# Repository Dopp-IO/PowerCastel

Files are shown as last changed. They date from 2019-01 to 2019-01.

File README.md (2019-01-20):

# PowerCastel
Tiny castellated adaptation of Adafruit PowerBoost 1000C.

Part	Value	        Package  
C1	  10uF	        C0603  
C2  	2.2uF	        C0603  
C4	  0.1uF       	C0603  
C6  	100uF	        C0805  
C7  	10uF	        C0603  
L1  	6.8uH	        INDUCTOR_5X5MM_TDK_VLC5045  
R1  	1.87M	        R0603  
R2  	340K	        R0603  
R3  	1.87M	        R0603  
R4  	200K	        R0603  
R6  	270K	        R0603  
R7  	100K	        R0603  
R13 	200K	        R0603  
R16 	1.0K	        R0603  
R17 	100K	        R0603  
THERM	15K	          R0603  
T1    MMUN2114      SC59-BEC  
U1	  TPS61090RSAR	PVQFN-16  
U2	  MCP73871	    QFN20_4MM

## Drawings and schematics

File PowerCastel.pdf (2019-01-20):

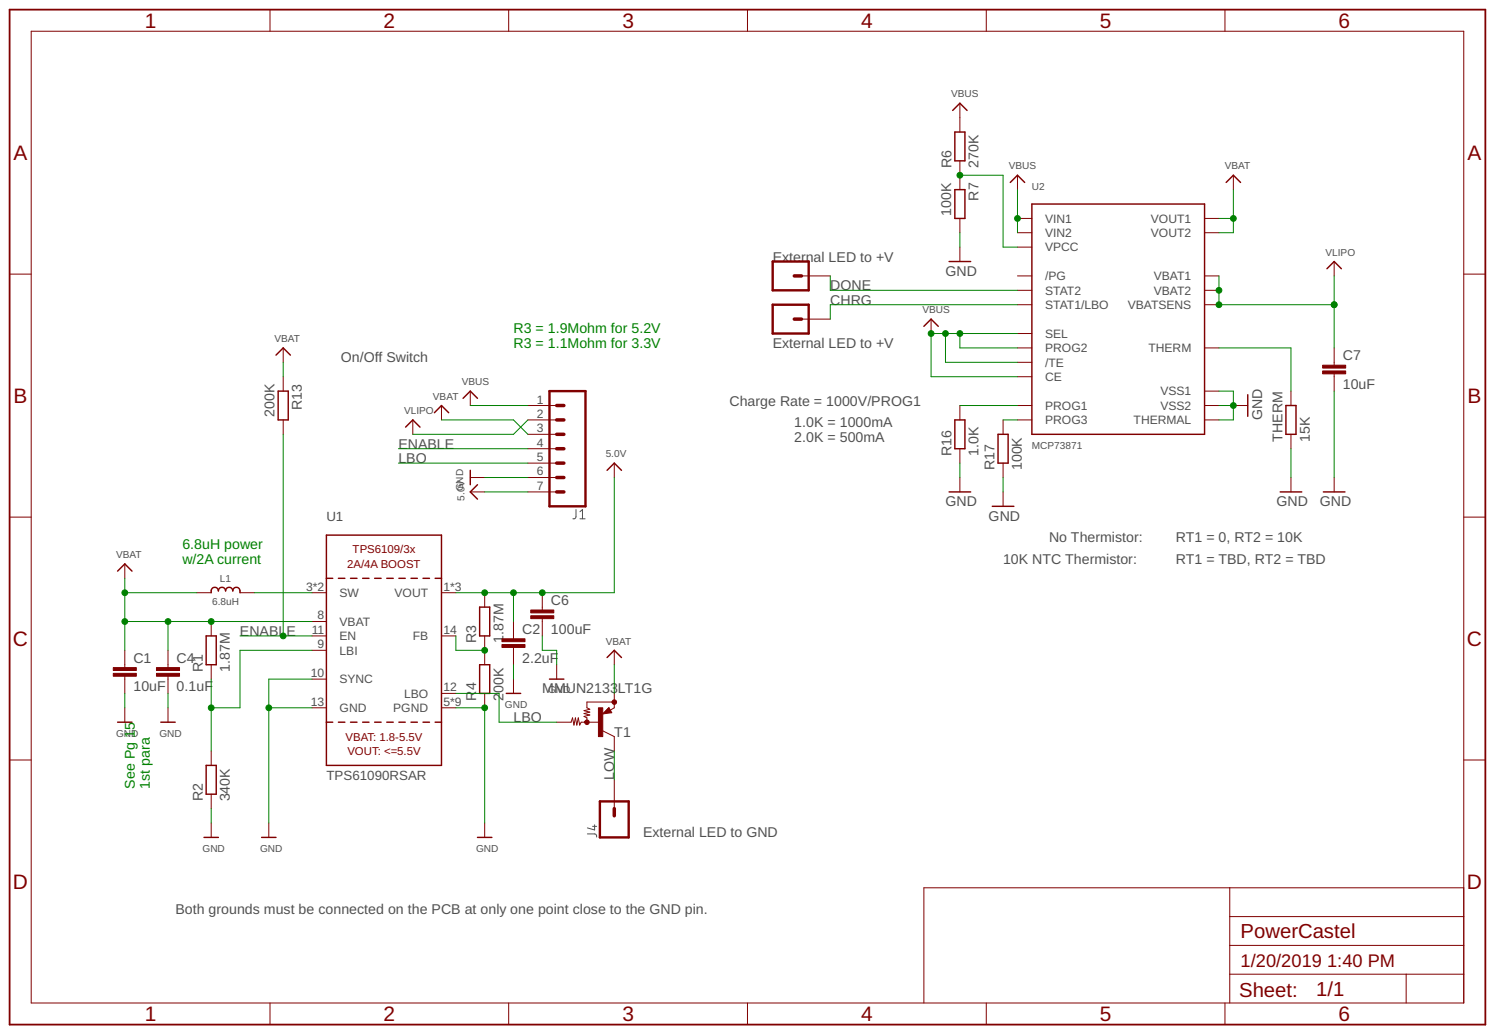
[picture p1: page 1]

External LED to GND

Both grounds must be connected on the PCB at only one point close to the GND pin.

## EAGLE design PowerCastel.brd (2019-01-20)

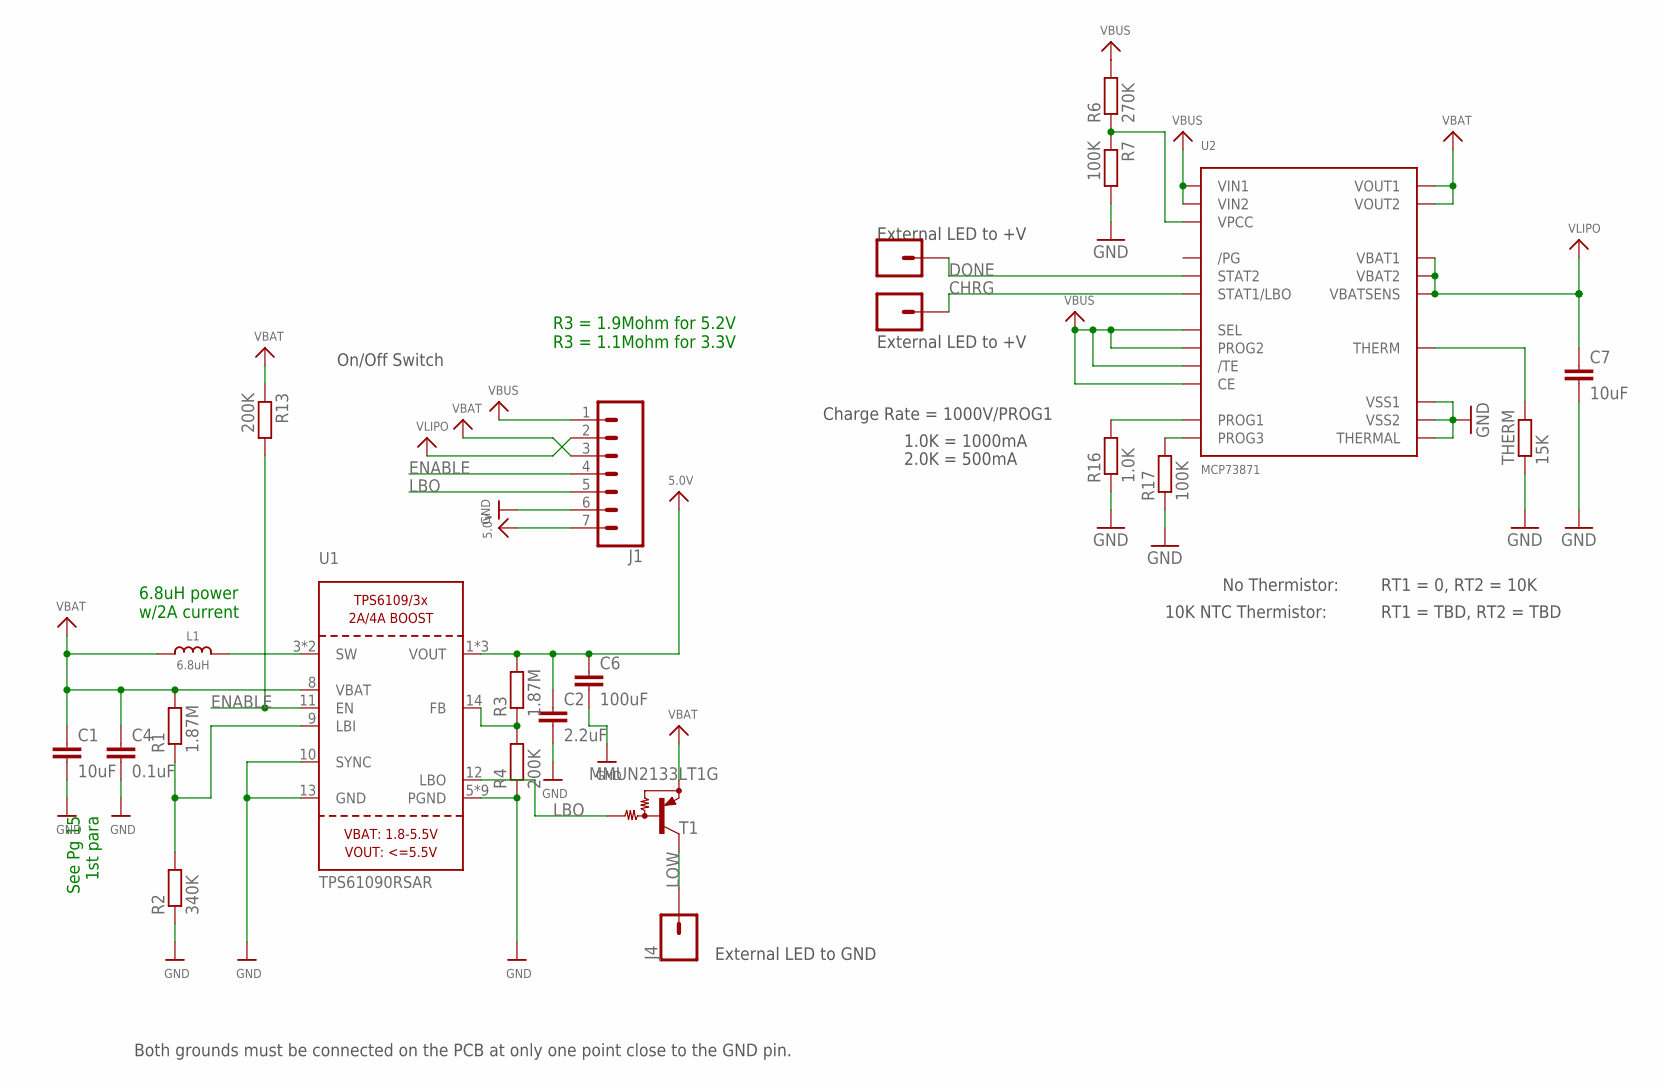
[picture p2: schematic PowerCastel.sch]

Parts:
C1, C7: 10uF; C0603
C2: 2.2uF; C0603
C4: 0.1uF; C0603
C6: 100uF; C0805
J1: CONN_07NO_SILK; 1X07_NO_SILK
J2, J3, J4: CONN_01PTH_NO_SILK_YES_STOP; 1X01_NO_SILK
L1: 6.8uH; INDUCTOR_5X5MM_TDK_VLC5045
R1, R3: 1.87M; R0603
R2: 340K; R0603
R4, R13: 200K; R0603
R6: 270K; R0603
R7, R17: 100K; R0603
R16: 1.0K; R0603
T1: MMUN2133LT1G; SC59-BEC
THERM: 15K; R0603
U1: TPS61090RSAR; PVQFN-16
U2: MCP73871; QFN20_4MM

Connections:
5.0V: C2.1, C6.1, J1.7, R3.2, U1.1 (VOUT), U1.15 (VOUT), U1.16 (VOUT)
CHRG: J3.1, U2.P$8 (STAT1/LBO)
DONE: J2.1, U2.P$7 (STAT2)
ENABLE: J1.4, R13.2, U1.11 (EN)
GND: C1.2, C2.2, C4.2, C6.2, C7.2, J1.6, R2.1, R4.1, R7.2, R16.1, R17.1, THERM.1, U1.5 (PGND), U1.6 (PGND), U1.7 (PGND), U1.10 (SYNC), U1.13 (GND), U1.P$18 (PGND), U1.P$19 (PGND), U1.P$20 (PGND), U1.P$21 (PGND), U1.P$22 (PGND), U1.THERMAL (PGND), U2.P$10 (VSS1), U2.P$11 (VSS2), U2.P$21 (THERMAL)
LBO: J1.5, T1.B, U1.12 (LBO)
LOW: J4.1, T1.C
unnamed: L1.P$2 (2), U1.3 (SW), U1.4 (SW)
unnamed: R1.1, R2.2, U1.9 (LBI)
unnamed: R3.1, R4.2, U1.14 (FB)
unnamed: R6.1, R7.1, U2.P$2 (VPCC)
unnamed: THERM.2, U2.P$5 (THERM)
unnamed: R17.2, U2.P$12 (PROG3)
unnamed: R16.2, U2.P$13 (PROG1)
VBAT: C1.1, C4.1, J1.3, L1.P$1 (1), R1.2, R13.1, T1.E, U1.8 (VBAT), U2.P$1 (VOUT1), U2.P$20 (VOUT2)
VBUS: J1.1, R6.2, U2.P$3 (SEL), U2.P$4 (PROG2), U2.P$9 (/TE), U2.P$17 (CE), U2.P$18 (VIN1), U2.P$19 (VIN2)
VLIPO: C7.1, J1.2, U2.P$14 (VBAT1), U2.P$15 (VBAT2), U2.P$16 (VBATSENS)

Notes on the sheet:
Both grounds must be connected on the PCB at only one point close to the GND pin.
On/Off Switch
See Pg 15 1st para
6.8uH power w/2A current
R3 = 1.9Mohm for 5.2V R3 = 1.1Mohm for 3.3V
Charge Rate = 1000V/PROG1
1.0K = 1000mA
2.0K = 500mA
No Thermistor:
10K NTC Thermistor:
RT1 = 0, RT2 = 10K
RT1 = TBD, RT2 = TBD
External LED to GND
External LED to +V

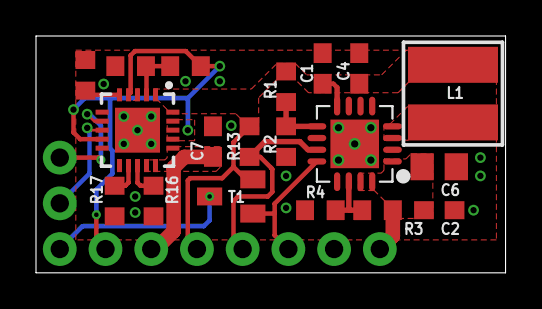
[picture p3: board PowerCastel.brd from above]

Board: 2 copper layers, 26.1 x 13.2 mm, 23 parts (0 on the bottom side), 17 nets.

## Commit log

2018-08-11 Added eagles, gerbers and pdf
    [PowerCastel.brd, PowerCastel.sch]
2018-08-11 Added BOM
2018-08-12 Fixed ground planes and added power planes
    Ground plane connection to components on left side of board has been widened. Added power planes as specified by TPS61090 datasheet.
    [PowerCastel.brd]
2018-08-12 Fixed ground via
    [PowerCastel.brd]
2019-01-20 Updated design
    New design has improved ground plane and has better support for external LEDs.
    [PowerCastel.brd, PowerCastel.sch]
2019-01-20 Updated schematic
    Includes PNP LED driver

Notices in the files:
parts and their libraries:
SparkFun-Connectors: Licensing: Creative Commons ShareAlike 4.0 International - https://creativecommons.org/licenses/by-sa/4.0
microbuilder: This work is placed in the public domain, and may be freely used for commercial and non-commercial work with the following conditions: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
